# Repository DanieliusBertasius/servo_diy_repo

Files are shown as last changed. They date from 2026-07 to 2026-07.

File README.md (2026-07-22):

Note to self: add ground test points in upcoming projects

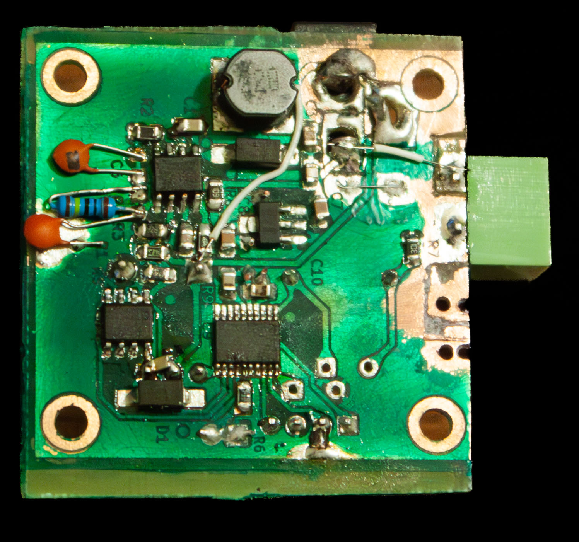
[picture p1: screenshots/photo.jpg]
Finished PCB photo


<br>
PSU:

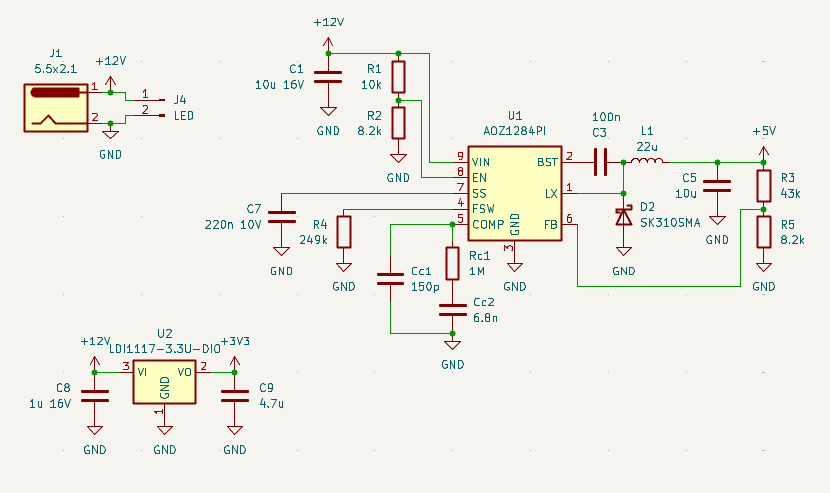
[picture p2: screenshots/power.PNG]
Power schematic


<br>
MCU:

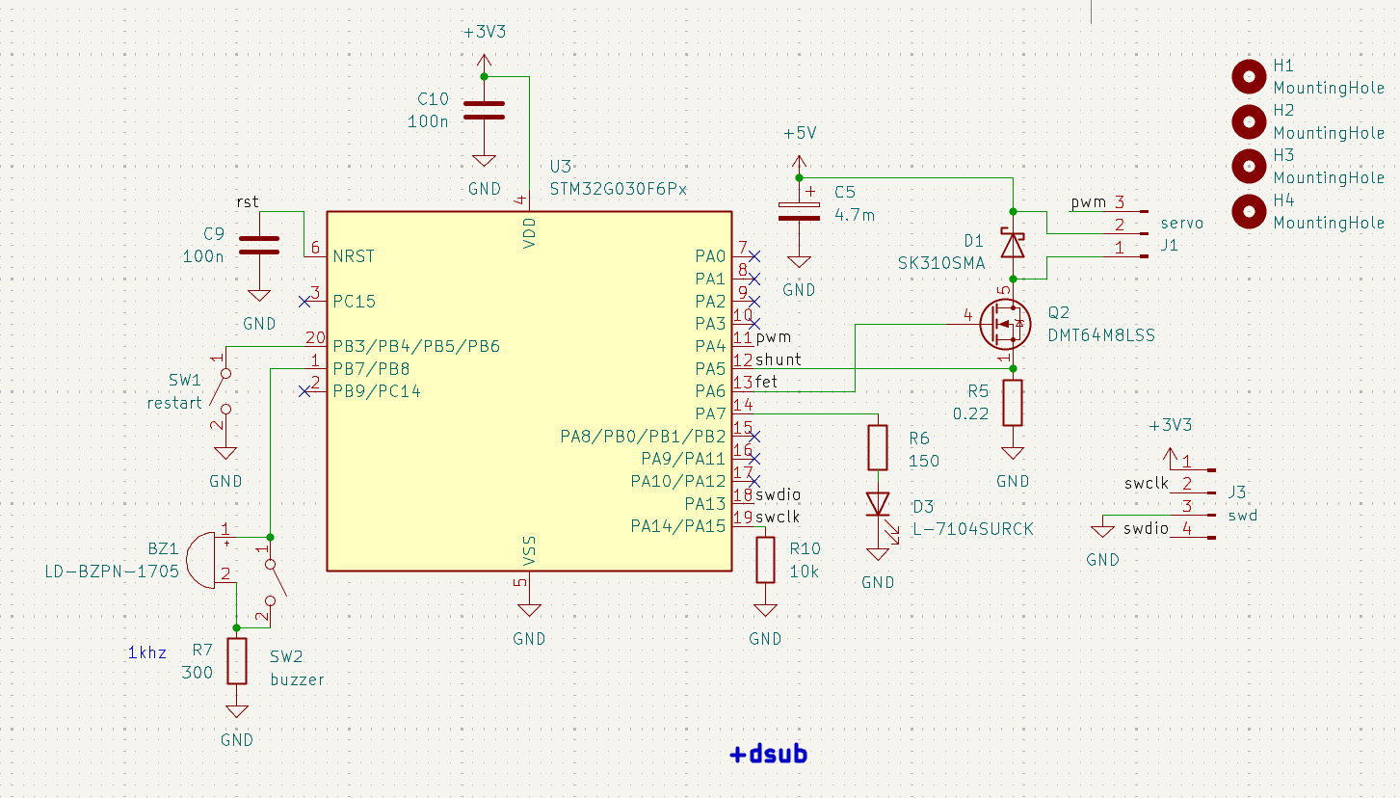
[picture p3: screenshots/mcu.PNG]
MCU schematic

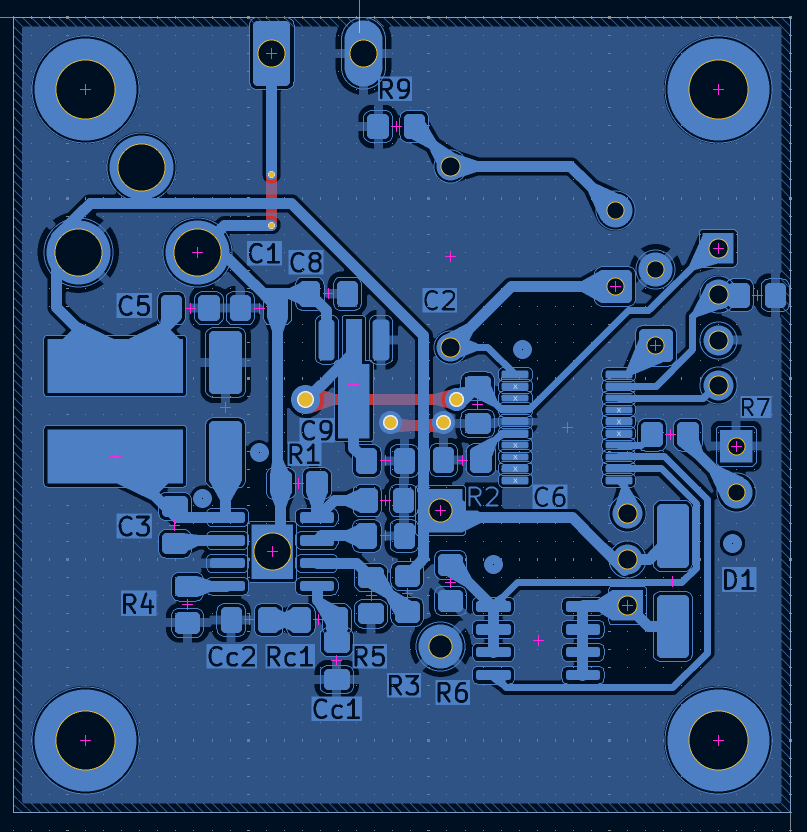
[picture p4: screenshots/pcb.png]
PCB

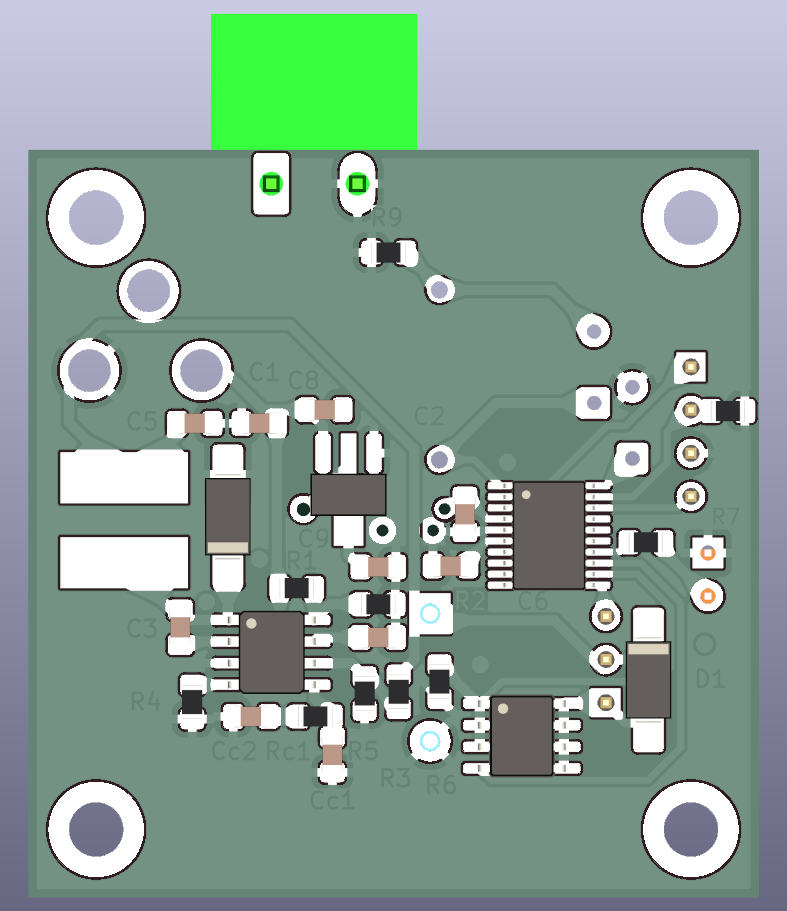
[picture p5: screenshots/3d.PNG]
3D view


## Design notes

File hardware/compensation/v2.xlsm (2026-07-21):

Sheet: User Guide
 | EZbuck Design Sheet Directions |  |  | Rev.1.0
The spreadsheet was design to help quickly implement the AOZ1284PI EZbuck controllers in a DC/DC converter using a buck converter.
The spreadsheet requires Iteration to be enabled to operate correctly.This is done through"Tools/Options/Calculation, select "Iteration", set the "Maximum iteration" to"1000" and the "Maximum change" to"0.0001".
The design tool will generate a recommended design that includes the loop compensation parameters and the calculated efficiency.The recommended values in the design may not be practical, yet the operation of the converter can be altered by using the closest parameter.
Input converter parameters: |  | Select buck regulator IC: | Pick the IC you want to design with.
 |  | Input voltage: | Which is converter input voltage.
 |  | Output voltage: | Which is converter output voltage.
 |  | Maximum output current: | Which is converter maximum output current.
 |  | Maximum output voltage ripple%: | Which is the output voltage ripple ratio.
 |  | Ambient temperature: | Which is the converter ambient temperature.
To use the design tool, enter data in the cells with the yellow text, the calculated values are in the cells with blue text. Red font indicate illegal input or potential design problems.

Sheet: EZBuck design calculator
7
EZBuck Design Spreadsheet |  | Rev. 1.0
Yellow cell | is the input parameters
Blue cell | is the calculated parameters
 | is the cell with comment |  | Step1: Buck regulator IC selection
 |  |  | 4
Typical application schematic
 |  |  | Step2: Define the system specification
 |  |  | Enter Application Parameters
 |  |  | Input Voltage: | 12 | V
 |  |  | Output Voltage: | 5 | V
 |  |  | Maximum Output Current: | 0.8 | A
 |  |  | Maximum Output Voltage Ripple%: | 3 | %
 |  |  | Ambient Temperature | 25 | ℃
 |  |  | Step3: RF selection
 |  |  | Switching Frequency needed: | 200 | kHz
 |  |  | Rcommend value for RF : | 250 | kΩ
 |  |  | Step4: Power stage component selection
 |  |  | Inductor Selection (L1)
 |  |  | Recommended L: | 10.42 | µH
 |  |  | Recommended ISATURATE: | 6.00 | A
 |  |  | Enter The Chosen Inductor Value: | 22 | µH
 |  |  | Enter The DCR of Chosen Inductor: | 100 | mΩ
 |  |  | Diode Selection (D1)
 |  |  | Enter The Diode Saturation Voltage: | 0.4 | V
Calculated Efficiency vs Load Current |  |  | Capacitor Selection (CIN and CO)
 |  |  | Minimum Recommended Input Capacitance: | 22 | µF
 |  |  | Minimum Input Capacitor RMS current rating: | 0.39 | Arms
 |  |  | Minimum Recommended Output Capacitance: | 2.761994949 | µF
 |  |  | Maximum Output Capacitor ESR: | 226.2857143 | mΩ
 |  |  | Enter The chosen Output Capacitor Value: | 4700 | µF
 |  |  | Enter The chosen Output Capacitor ESR: | 1 | mΩ
 |  |  | Output Voltage Characteristics
 |  |  | Estimated Output Voltage Ripple: | 0.7510275629 | mV
 |  |  | Step5: Control component selection
 |  |  | Feedback Resistors Selection(RFB1, RFB2)
 |  |  | Enter a Value for RFB2: | 10 | kΩ
 |  |  | Recommended Value for RFB1: | 52.5 | kΩ
 |  |  | Compensation Component Selection (RC, CC1, CC2)
 |  |  | Enter Desired Crossover Frequency: | 10 | kHz
Calculated Bode Plot |  |  | Recommended Value for CC1: | 7.076351534 | nF
 |  |  | Recommended Value for RC: | 1153.360716 | kΩ
 |  |  | Recommended Value for CC2: | 0 | pF
 |  |  | Recommend Value for Cfeedforward: | 2288.770822 | pF
 |  |  | Enter The Chosen Value for CC1: | 6.8 | nF
 |  |  | Enter The Chosen Value for RC: | 1000 | kΩ
 |  |  | Enter The Chosen Value for CC2: | 150 | pF
 |  |  | Enter The Chosen Value for Cfeedforward: | 0 | pF
 |  |  | Loop Characteristics
 |  |  | Expected Crossover Frequency: | 3.3113 | kHz
 |  |  | Expected Phase Margin: | 11.49938081 | °
 |  |  | Step6: Thermal Performance
 |  |  | Thermal Characteristics
 |  |  | Internal Power Dissipation: | 0.04050994562 | W
 |  |  | Junction Temperature: | 27.51161663 | ℃
 |  |  | For datasheets,evaluation note,please visit: www.aosmd.com (http://www.aosmd.com/web/products/poweric.jsp)

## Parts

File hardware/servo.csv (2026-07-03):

Id | Designator | Footprint | Quantity | Designation
1 | BZ1 | LOUDITY LD-BZPN-1705 | 1 | LD-BZPN-1705
2 | C1, C9, C10 | C_0805_2012Metric_Pad1.18x1.45mm_HandSolder | 3 | 100n
3 | C2 | C_0805_2012Metric_Pad1.18x1.45mm_HandSolder | 1 | 10u 16V
4 | C3 | C_0805_2012Metric_Pad1.18x1.45mm_HandSolder | 1 | 10u
5 | C4 | C_0805_2012Metric_Pad1.18x1.45mm_HandSolder | 1 | 220n 10V
6 | C5 | CP_Radial_D16.0mm_P7.50mm | 1 | 4.7m
7 | C6 | C_0805_2012Metric_Pad1.18x1.45mm_HandSolder | 1 | 1.5n
8 | C7 | C_0805_2012Metric_Pad1.18x1.45mm_HandSolder | 1 | 1u 16V
9 | C8 | C_0805_2012Metric_Pad1.18x1.45mm_HandSolder | 1 | 4.7u
10 | D1, D2 | D_SMA_Handsoldering | 2 | SK310SMA
11 | D3 | LED_D3.0mm | 1 | L-7104SURCK
12 | J1 | PinHeader_1x03_P2.54mm_Vertical | 1 | servo
13 | J2 | BarrelJack_CUI_PJ-102AH_Horizontal | 1 | Jack-DC
14 | J3 | PinHeader_1x04_P2.54mm_Vertical | 1 | swd
15 | L1 | LD2-HV | 1 | 22u
16 | Q2 | SOIC-8_3.9x4.9mm_P1.27mm | 1 | DMT64M8LSS
17 | R1 | R_0805_2012Metric_Pad1.20x1.40mm_HandSolder | 1 | 43k
18 | R2 | R_0805_2012Metric_Pad1.20x1.40mm_HandSolder | 1 | 249k
19 | R3, R9 | R_0805_2012Metric_Pad1.20x1.40mm_HandSolder | 2 | 8.2k
20 | R4, R8 | R_0805_2012Metric_Pad1.20x1.40mm_HandSolder | 2 | 10k
21 | R5 | R_0805_2012Metric_Pad1.20x1.40mm_HandSolder | 1 | 0.22
22 | R6 | R_0805_2012Metric_Pad1.20x1.40mm_HandSolder | 1 | 1.3k
23 | R7 | R_0805_2012Metric_Pad1.20x1.40mm_HandSolder | 1 | 51k
24 | SW1 | SolderWire-0.25sqmm_1x02_P4.2mm_D0.65mm_OD1.7mm | 1 | restart
25 | SW2 | SolderWire-0.25sqmm_1x02_P4.2mm_D0.65mm_OD1.7mm | 1 | buzzer
26 | U1 | SOIC-8-1EP_3.9x4.9mm_P1.27mm_EP2.71x3.7mm | 1 | AOZ1284PI
27 | U3 | TSSOP-20_4.4x6.5mm_P0.65mm | 1 | STM32G030F6Px
28 | U4 | SOT-89-3_Handsoldering | 1 | LDI1117-3.3U-DIO

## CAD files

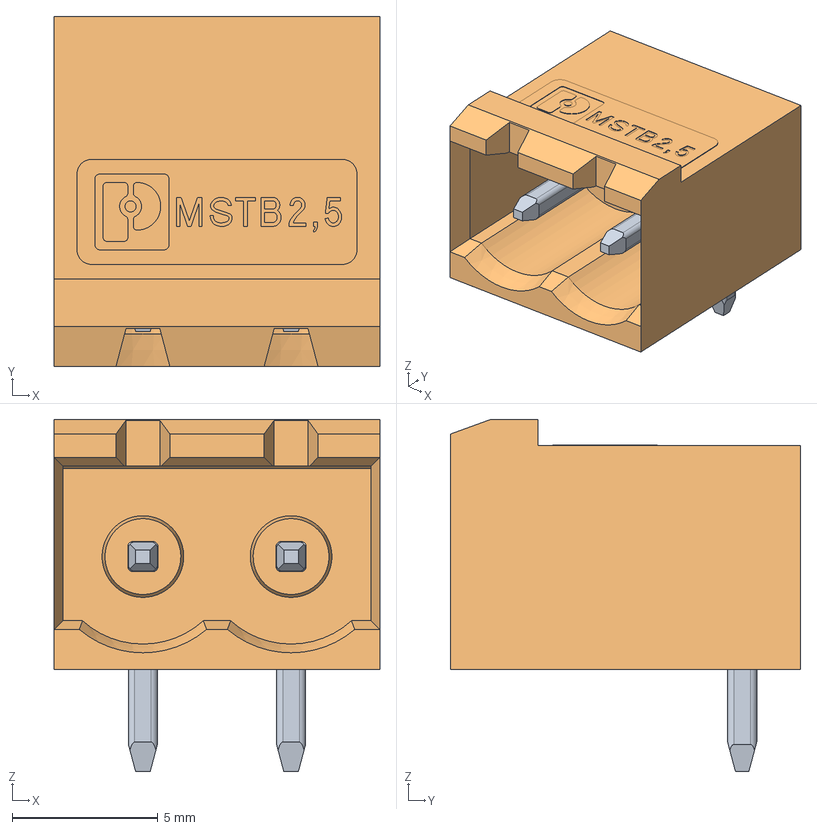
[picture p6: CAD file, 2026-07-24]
hardware/3D/for assembly/terminal.step
11.2 x 12.0 x 12.1 mm

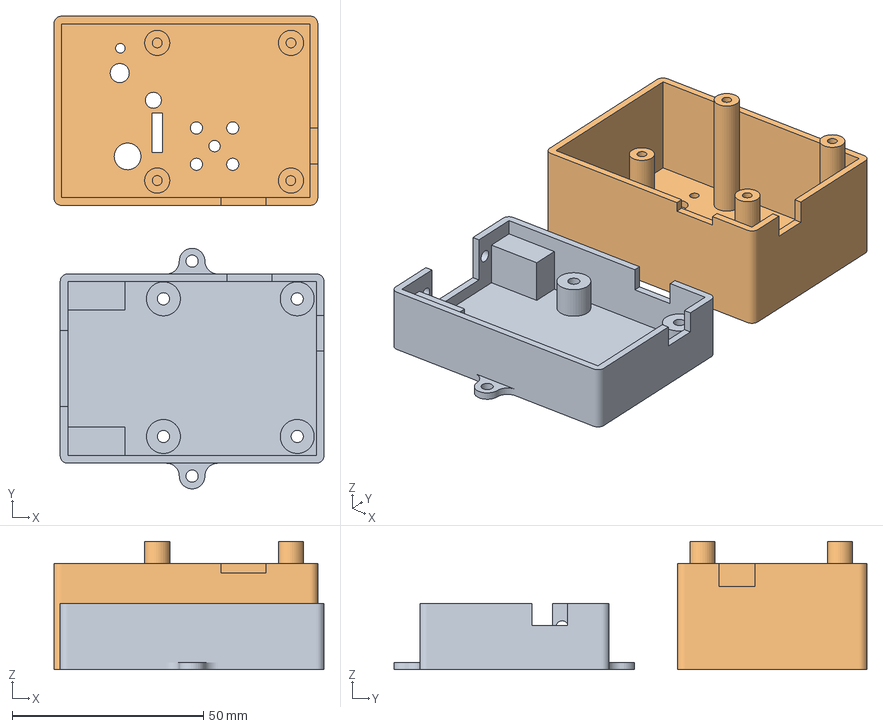
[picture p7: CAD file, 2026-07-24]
hardware/3D/servo_ender.3mf
70.6 x 123.6 x 33.6 mm
bottom.stl
top.stl

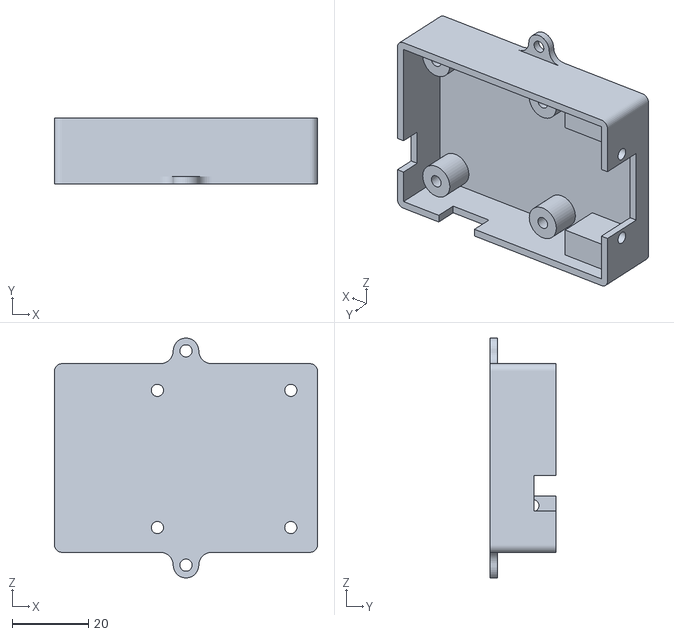
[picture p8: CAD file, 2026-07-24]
hardware/3D/bottom.stl
69.0 x 17.3 x 62.9

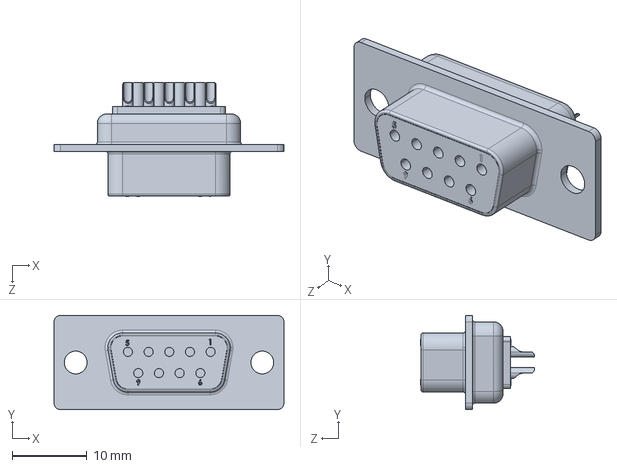
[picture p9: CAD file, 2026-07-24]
hardware/3D/for assembly/dsub.STEP
30.8 x 12.6 x 15.3 mm

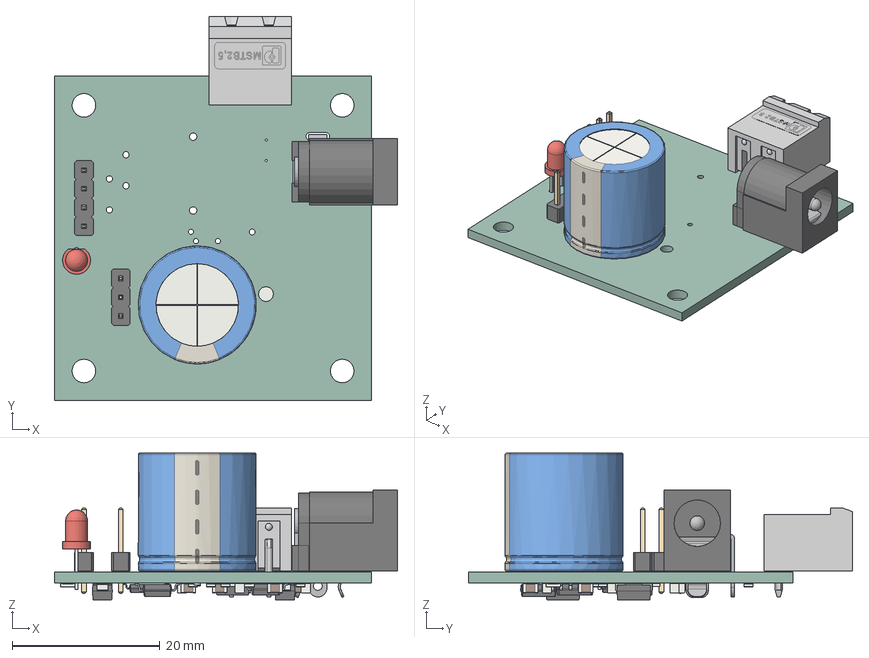
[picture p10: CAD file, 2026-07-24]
hardware/3D/for assembly/pcb.step
46.5 x 52.0 x 19.9 mm
(Unsaved)
LED_D3.0mm
CP_Radial_D160mm_P750mm
PinHeader_1x04_P254mm_Vertical
PinHeader_1x03_P254mm_Vertical
BarrelJack_GCT_DCJ200-10-A_Horizontal
C_0805_2012Metric x 10
R_0805_2012Metric x 10
adbeea57-9c39-11ed-93f0-dde97e994e83_part
adbeea58-9c39-11ed-93f0-dde97e994e83_part
adbeea59-9c39-11ed-93f0-dde97e994e83_part
SOIC-8-1EP_3.9x4.9mm_P1.27mm_EP2.29x3mm
D_SMA x 2
TSSOP-20_4.4x6.5mm_P0.65mm
SOIC-8_3.9x4.9mm_P1.27mm
servo_PCB

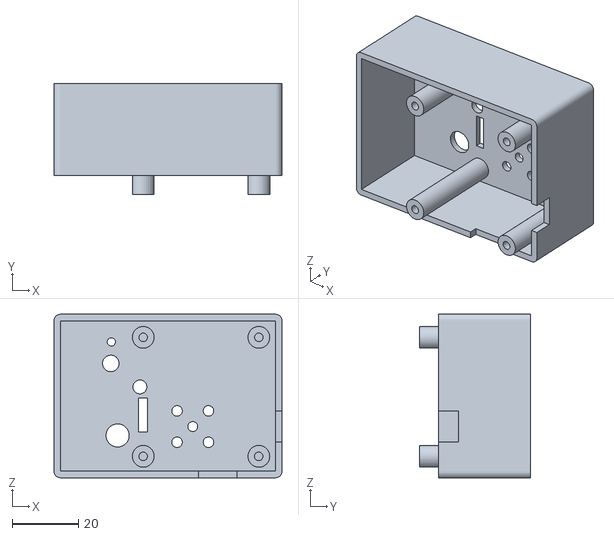
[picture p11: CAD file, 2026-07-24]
hardware/3D/top.stl
69.0 x 33.6 x 49.5

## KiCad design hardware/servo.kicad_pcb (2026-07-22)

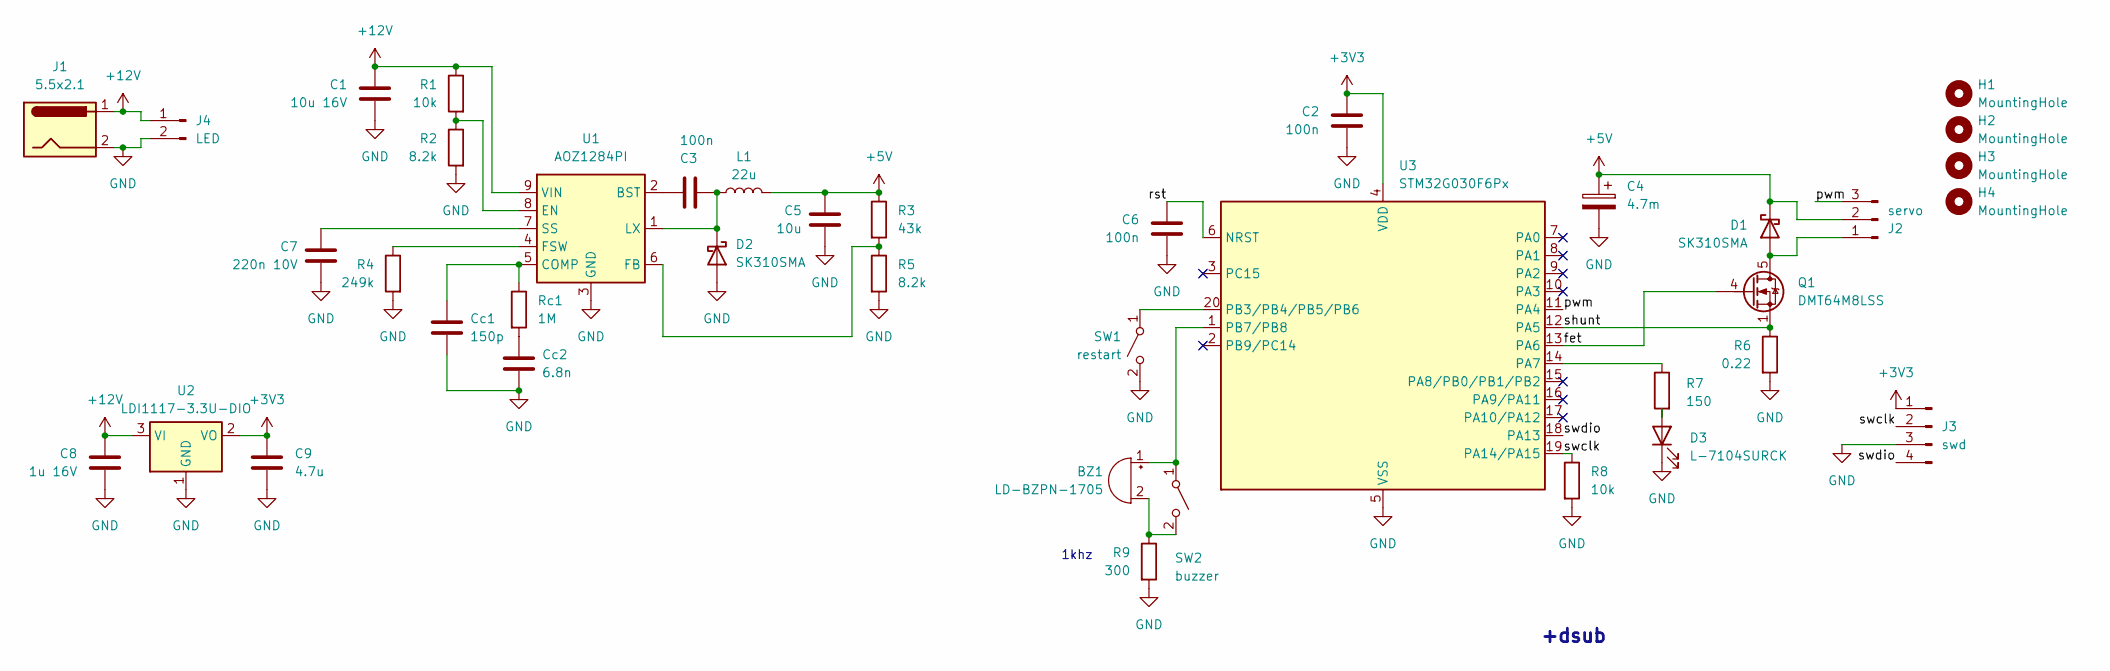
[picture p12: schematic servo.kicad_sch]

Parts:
BZ1: LD-BZPN-1705; LOUDITY LD-BZPN-1705
C1: 10u 16V; C_0805_2012Metric_Pad1.18x1.45mm_HandSolder
C2, C3, C6: 100n; C_0805_2012Metric_Pad1.18x1.45mm_HandSolder
C4: 4.7m; CP_Radial_D16.0mm_P7.50mm
C5: 10u; C_0805_2012Metric_Pad1.18x1.45mm_HandSolder
C7: 220n 10V; C_0805_2012Metric_Pad1.18x1.45mm_HandSolder
C8: 1u 16V; C_0805_2012Metric_Pad1.18x1.45mm_HandSolder
C9: 4.7u; C_0805_2012Metric_Pad1.18x1.45mm_HandSolder
Cc1: 150p; C_0805_2012Metric_Pad1.18x1.45mm_HandSolder
Cc2: 6.8n; C_0805_2012Metric_Pad1.18x1.45mm_HandSolder
D1, D2: SK310SMA; D_SMA_Handsoldering
D3: L-7104SURCK; LED_D3.0mm
H1, H2, H3, H4: MountingHole; MountingHole_3.2mm_M3_DIN965_Pad_TopOnly
J1: 5.5x2.1; BarrelJack_diy
J2: servo; PinHeader_1x03_P2.54mm_Vertical
J3: swd; PinHeader_1x04_P2.54mm_Vertical
J4: LED; PhoenixContact_MSTBA_2,5_2-G-5,08_1x02_P5.08mm_Horizontal
L1: 22u; LD2-HV
Q1: DMT64M8LSS; SOIC-8_3.9x4.9mm_P1.27mm
R1, R8: 10k; R_0805_2012Metric_Pad1.20x1.40mm_HandSolder
R2, R5: 8.2k; R_0805_2012Metric_Pad1.20x1.40mm_HandSolder
R3: 43k; R_0805_2012Metric_Pad1.20x1.40mm_HandSolder
R4: 249k; R_0805_2012Metric_Pad1.20x1.40mm_HandSolder
R6: 0.22; R_0805_2012Metric_Pad1.20x1.40mm_HandSolder
R7: 150; R_0805_2012Metric_Pad1.20x1.40mm_HandSolder
R9: 300; R_0805_2012Metric_Pad1.20x1.40mm_HandSolder
Rc1: 1M; R_0805_2012Metric_Pad1.20x1.40mm_HandSolder
SW1: restart; SolderWire-0.25sqmm_1x02_P4.2mm_D0.65mm_OD1.7mm
SW2: buzzer; SolderWire-0.25sqmm_1x02_P4.2mm_D0.65mm_OD1.7mm
U1: AOZ1284PI; SOIC-8-1EP_3.9x4.9mm_P1.27mm_EP2.29x3mm_diy
U2: LDI1117-3.3U-DIO; SOT-89-3_Handsoldering
U3: STM32G030F6Px; TSSOP-20_4.4x6.5mm_P0.65mm

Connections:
+3V3: C2.1, C9.1, J3.1, U2.2 (VO), U3.4 (VDD)
+5V: C4.1, C5.1, D1.1 (K), J2.2, L1.2, R3.1
+12V: C1.1, C8.1, J1.1, J4.1, R1.1, U1.9 (VIN), U2.3 (VI)
/fet: Q1.4 (G), U3.13 (PA6)
/pwm: J2.3, U3.11 (PA4)
/rst: C6.1, U3.6 (NRST)
/shunt: Q1.1 (S), Q1.2 (S), Q1.3 (S), R6.1, U3.12 (PA5)
/swclk: J3.2, R8.1, U3.19 (PA14/PA15)
/swdio: J3.4, U3.18 (PA13)
GND: C1.2, C2.2, C4.2, C5.2, C6.2, C7.2, C8.2, C9.2, Cc1.2, Cc2.2, D2.2 (A), D3.1 (K), J1.2, J3.3, J4.2, R2.2, R4.2, R5.2, R6.2, R8.2, R9.2, SW1.2 (B), U1.3 (GND), U2.1 (GND), U3.5 (VSS)
unnamed: BZ1.1 (+), SW2.1 (A), U3.1 (PB7/PB8)
unnamed: BZ1.2 (-), R9.1, SW2.2 (B)
unnamed: Cc2.1, Rc1.2
unnamed: D1.2 (A), J2.1, Q1.5 (D), Q1.6 (D), Q1.7 (D), Q1.8 (D)
unnamed: C3.2, D2.1 (K), L1.1, U1.1 (LX)
unnamed: D3.2 (A), R7.2
unnamed: SW1.1 (A), U3.20 (PB3/PB4/PB5/PB6)
unnamed: C3.1, U1.2 (BST)
unnamed: Cc1.1, Rc1.1, U1.5 (COMP)
unnamed: R1.2, R2.1, U1.8 (EN)
unnamed: R3.2, R5.1, U1.6 (FB)
unnamed: R4.1, U1.4 (FSW)
unnamed: C7.1, U1.7 (SS)
unnamed: R7.1, U3.14 (PA7)

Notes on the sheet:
1khz
+dsub

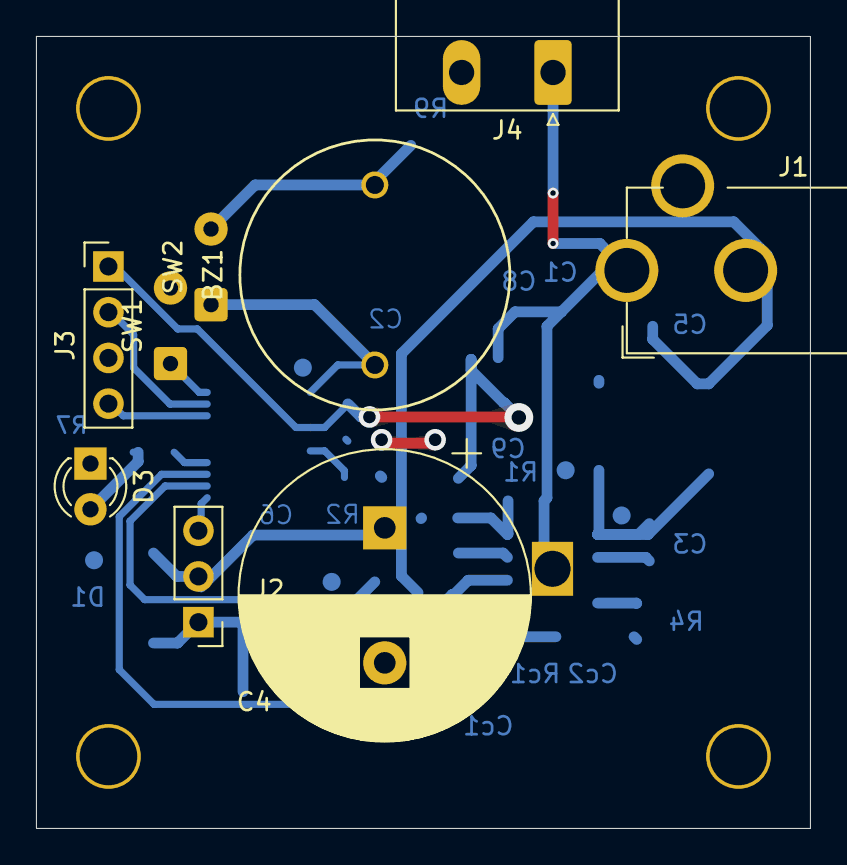
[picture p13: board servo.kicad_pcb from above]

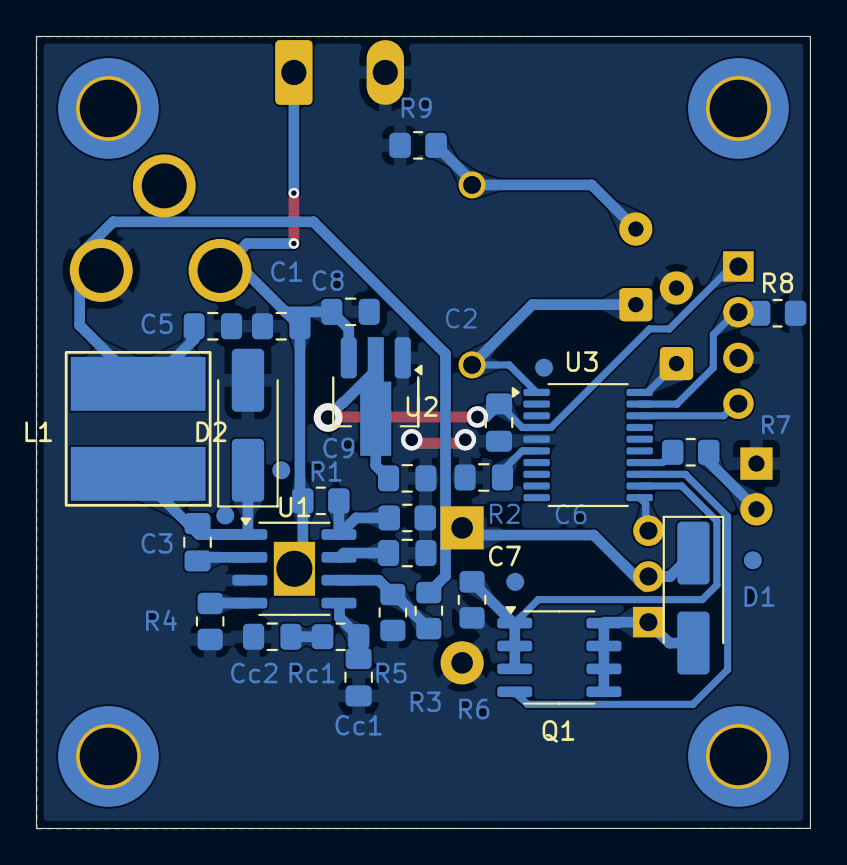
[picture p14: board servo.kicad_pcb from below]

Board: 2 copper layers, 43.0 x 44.0 mm, 40 parts (31 on the bottom side), 24 nets.

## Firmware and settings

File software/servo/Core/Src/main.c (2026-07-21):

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
/* Includes ------------------------------------------------------------------*/
#include "main.h"

/* USER CODE BEGIN PD */
#define I_STALL 0.8
#define R_SHUNT 0.22
#define THRESHOLD I_STALL*R_SHUNT/3.3*4095
#define SAMPLES 3 //ignored samples
/* USER CODE END PD */

ADC_HandleTypeDef hadc1;

TIM_HandleTypeDef htim14;
TIM_HandleTypeDef htim16;

/* USER CODE BEGIN PV */
volatile uint8_t servo_power_rdy=0,angle=90,direction=1,buzzer=0,count=0;
volatile uint32_t last_debounce=0,tick=0;
/* USER CODE END PV */

void SystemClock_Config(void);
static void MX_GPIO_Init(void);
static void MX_ADC1_Init(void);
static void MX_TIM14_Init(void);
static void MX_TIM16_Init(void);
/**
  * @brief  The application entry point.
  * @retval int
  */
int main(void)
{

  /* MCU Configuration--------------------------------------------------------*/

  /* Reset of all peripherals, Initializes the Flash interface and the Systick. */
  HAL_Init();

  /* Configure the system clock */
  SystemClock_Config();

  /* Initialize all configured peripherals */
  MX_GPIO_Init();
  MX_ADC1_Init();
  MX_TIM14_Init();
  MX_TIM16_Init();
  /* USER CODE BEGIN 2 */
  HAL_TIM_PWM_Start(&htim14, TIM_CHANNEL_1);
  HAL_TIM_Base_Start_IT(&htim14);
  HAL_TIM_Base_Start_IT(&htim16);
  /* USER CODE END 2 */

  /* Infinite loop */
  /* USER CODE BEGIN WHILE */
  while (1)
  {
	TIM14->CCR1 = (angle/180.0*0.09+0.03)*65535;
    /* USER CODE END WHILE */

    /* USER CODE BEGIN 3 */
  }
  /* USER CODE END 3 */
}

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
/* USER CODE BEGIN 4 */
void HAL_ADC_ConvCpltCallback(ADC_HandleTypeDef* hadc)
{
    if(HAL_ADC_GetValue(&hadc1)>THRESHOLD){
    	count++;
    }
    else{
    	count=0;
    }
    if(count>SAMPLES){
    	buzzer=1;
    }
}
void HAL_GPIO_EXTI_Falling_Callback(uint16_t GPIO_Pin)
{
	HAL_NVIC_DisableIRQ(EXTI2_3_IRQn);
	last_debounce=HAL_GetTick();
	HAL_GPIO_WritePin(fet_GPIO_Port, fet_Pin, 1);
	HAL_TIM_PWM_Start(&htim14, TIM_CHANNEL_1);
	HAL_GPIO_WritePin(led_GPIO_Port, led_Pin, 0);
	buzzer=0;
}
void HAL_TIM_PeriodElapsedCallback(TIM_HandleTypeDef* htim)
{
	if(htim->Instance == TIM16){
		if(buzzer){
			HAL_GPIO_TogglePin(buzzer_GPIO_Port, buzzer_Pin);
		}
		else{
			HAL_GPIO_WritePin(buzzer_GPIO_Port, buzzer_Pin, 0);
		}
	}
	else{
		if(buzzer){
			HAL_TIM_PWM_Stop(&htim14, TIM_CHANNEL_1); // servo control stop
			HAL_GPIO_WritePin(fet_GPIO_Port, fet_Pin, 0); // servo power cut
			HAL_GPIO_WritePin(led_GPIO_Port, led_Pin, 1); // alert LED on
		}
	}
}
/* USER CODE END 4 */
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


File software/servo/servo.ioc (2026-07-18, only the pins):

Mcu.UserName=STM32G030F6Px
PA13.Signal=SYS_SWDIO
PA14-BOOT0.Signal=SYS_SWCLK
PA4.Signal=S_TIM14_CH1
PA5.Signal=ADC1_IN5
PA6.GPIO_Label=fet
PA6.Signal=GPIO_Output
PA7.GPIO_Label=led
PA7.Signal=GPIO_Output
PB3.Signal=GPXTI3
PB7.GPIO_Label=buzzer
PB7.Signal=GPIO_Output

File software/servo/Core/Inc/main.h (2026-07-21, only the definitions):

#define buzzer_Pin GPIO_PIN_7
#define buzzer_GPIO_Port GPIOB
#define fet_Pin GPIO_PIN_6
#define fet_GPIO_Port GPIOA
#define led_Pin GPIO_PIN_7
#define led_GPIO_Port GPIOA
#define DEBOUNCE 500
#define SOFTSTART 100
#define ADCSTART (SOFTSTART+20)

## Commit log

2026-07-03 Add cubeide project, organize
    [servo.csv, servo.kicad_pcb, servo.kicad_sch]
2026-07-18 add code, 3d view, reorganize
    [servo.kicad_pcb]
2026-07-18 fix barrel jack footprint
    [servo.kicad_pcb, servo.kicad_sch]
2026-07-18 schematic cleanup, repo organizing
    [servo.kicad_sch]
2026-07-18 add NC flags, update README
    [servo.kicad_sch]
2026-07-20 Fix getting stuck in bootloader, false overcurrent triggers
    HARDWARE: add BOOT0 pulldown, reduce buzzer resistance for more volume, add drill hole for AOZ1284 footprint EPAD
    SOFTWARE: add ADC delay for motor inrush, add software lowpass filtering to overcurrent protection
    [servo.kicad_pcb, servo.kicad_sch]
2026-07-20 Save DC-DC calculator changes
    [Worksheet in EZBuckDesignTool-20230516.xlsm, senas.xlsm]
2026-07-21 Recalculate DC-DC compensation
    [Worksheet in EZBuckDesignTool-20230516.xlsm]
2026-07-21 Recalculate DC-DC compensation
    Recalculate DC-DC compensation for maximum capacitance
    [Worksheet in EZBuckDesignTool-20230516.xlsm]
2026-07-21 Hardware and software fixes, reorganize
    Recalculate compensation for 4.7mF, increase ADC delay, improve code readability, match compensation annotation in schematic to datasheet
    [Worksheet in EZBuckDesignTool-20230516.xlsm, senas.xlsm, servo.kicad_pcb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]
2026-07-21 Update screenshots, schematic readability
    [servo.kicad_sch]
2026-07-22 Add connector for LEDs, finished PCB picture
    Add connector for LED module, finished PCB picture, edit schematic for readability
    [servo.kicad_pcb, servo.kicad_sch]
2026-07-24 Add files for 3D printing
    [bottom.stl, dsub.STEP, pcb.step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]
2026-07-24 Add mounts to enclosure
    [bottom.stl, servo_bambu.3mf, servo_e5max.3mf]
2026-07-24 Add orcaslicer project and gcode
    [servo_ender.3mf]

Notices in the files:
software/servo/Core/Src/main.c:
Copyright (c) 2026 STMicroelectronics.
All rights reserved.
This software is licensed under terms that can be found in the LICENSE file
